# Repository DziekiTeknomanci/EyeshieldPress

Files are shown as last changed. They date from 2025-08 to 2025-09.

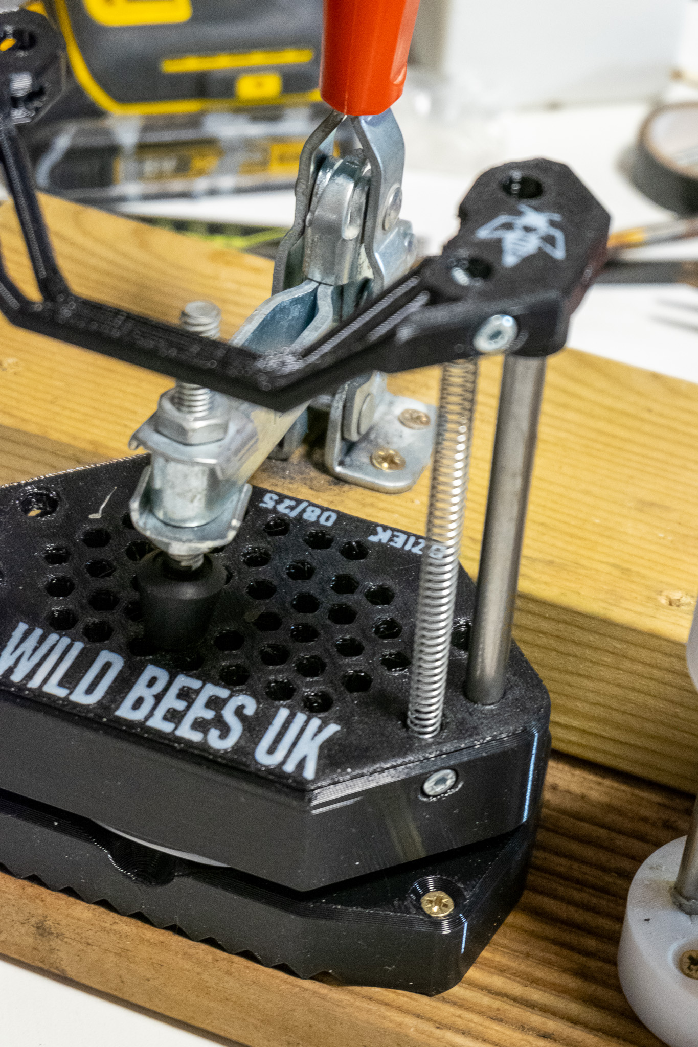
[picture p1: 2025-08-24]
Photos/DSCF0192.jpg

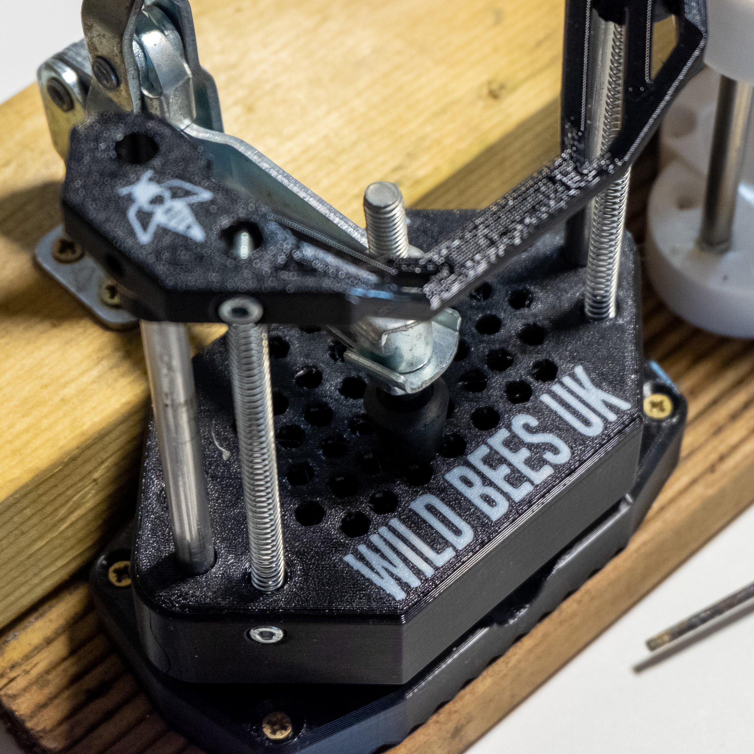
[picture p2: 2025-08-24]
Photos/DSCF0189.jpg

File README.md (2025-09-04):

## Bill of Materials (Hardware)

| Component | Qty | Example Link | Notes |
|---|:--:|---|---|
| M4 × 16 mm cap-head socket screws (CHSS) | 10 | [eBay](https://www.ebay.co.uk/itm/365366757336) | 20 mm also works. Cap-head looks neat, other heads are fine. |
| 8 mm linear rod, 150 mm length | 2 | [eBay](https://www.ebay.co.uk/itm/284132709444) | Cheaper in longer lengths—cut to size. (8 mm OD tube may work. Avoid threaded stud.) |
| LM8UU linear bearing | 2 | [eBay](https://www.ebay.co.uk/itm/283560168663) | Optional but highly recommended. |
| Expansion spring, 30–50 mm free length, 6–8 mm OD, 0.5–0.8 mm wire | 2–4 | [eBay](https://www.ebay.co.uk/itm/387764721266) | Two is usually enough; four anchor points allow tuning. |
| Toggle clamp | 1 | [Amazon](https://www.amazon.co.uk/dp/B08F4TG6J5) | Many types will work; large force not required. |

> You can modify the CAD to accommodate different hardware.

---

## Printed Parts & Settings

| Part | Qty | Walls | Solid Top/Bottom Layers | Infill | Notes |
|---|:--:|:--:|:--:|:--:|---|
| Press Bottom | 1 | 3 | 4 / 3 | Gyroid 10% (or Grid 20%) | — |
| Press Top | 1 | 3 | 3 / 4 | Gyroid 10% (or Grid 20%) | — |
| Press Cap | 1 | 3 | 3 / 3 | Gyroid 10% (or Grid 20%) | Tree support recommended for the overhang |
| Printed “Bearing” (optional) | 2 | 4 | 3 / 3 | **None (solid)** | Only if not using LM8UU; print at minimal layer height |

### Material Options
- **PETG** — Recommended for all parts.
- **PLA** — Works, but watch heat buildup; press faces may creep over time.
- **ABS** — Most durable; scale to ~**101%** or compensate for shrinkage in CAD.

### Logos/Text Variants
- *Plain:* Slice the “plain” STL, or in the 3MF set both “objects” to the same filament.
- *Embossed:* Delete the non-named objects in the 3MF; the text will be cut into the first layer.

### Printing With Contrast Colour
The logo/text versions use two bodies at Layer 1 so you can do a manual or automatic filament change for contrast. If you print **Top** and **Cap** together, you only need one change. PLA text on a PETG body is fine. Prefer the provided 3MF files so objects are already separated by filament.

---

## Tools & Consumables
- Soft hammer/mallet *(or steel hammer + wood block)*
- Vice or clamp *(for pressing LM8UU)*
- Lithium or other heavy grease *(light oil works but is sub-optimal)*
- 4×2″ timber off-cut (base & raised step)
- Hacksaw + sandpaper *(if cutting shafts)*
- **Optional:** M4 tap, 7.5 mm drill bit, 8 mm drill bit

---

## Assembly (≈10–20 min)

1. **Cut shafts (if needed).** If your 8 mm rod isn’t pre-cut, cut to **150 mm**. Tolerance is generous (> 10 mm), but make both the same length. Deburr and add a small chamfer with sandpaper. A cordless drill can act as a “lathe” while sanding.
2. **Prep threads.** *Press Top* and *Press Cap* include printed **M4** threads. Screws will self-tap; using an **M4 tap** makes it easier.
3. **Size holes.** Open up the outer holes on *Press Top* with an **8 mm** bit (hand-twisting is fine). Size the matching holes on *Press Bottom* and *Press Cap* to **7.5 mm** so the shafts fit tightly there.
4. **Install shafts (bottom).** Using a soft hammer, drive both shafts into the two large holes on *Press Bottom* until flush with the underside. Stack *Press Top* during this step to help alignment.
5. **Install bearings (top).** Pack **LM8UU** with heavy grease. Press them into the two 25 mm bores on *Press Top*. These are a friction fit—start gently with a mallet, then press fully using a vice or clamp.
6. **Assemble slide.** Carefully slide *Press Top* onto the shafts.
7. **Fit springs (lower).** Hook 2 springs into the lower anchor holes on *Press Top*. Pass the M4 socket screw through the spring loop and into the threaded hole. Do not overtighten. Up to 4 springs can be used.
8. **Fit cap.** Tap *Press Cap* onto the shaft ends. If loose, there is an **M4** hole to secure, but it’s usually not needed.
9. **Fit springs (upper).** Attach the spring tops to *Press Cap* as above.
10. **Mount to base.** Screw the press to a **wooden base**, then add a **raised “step”** 40–50 mm behind the base surface (a 4×2″ off-cut is perfect).
11. **Mount the toggle clamp.** Center the clamp over *Press Top* and adjust height so the press faces just meet. Extra clamp force only loads the press, not the work—there’s no benefit to overtightening and you can’t “over-press” the part unless you damage the tool.

---

## Tips
- Heavier grease inside LM8UU reduces rattle and wear; avoid losing balls from the open ends.
- If press fit tolerances are frustrating for your printer/material, consider lightly sanding bores or tweaking the CAD.
- Printed bushings work in a pinch but LM8UU will last longer and glide smoother.

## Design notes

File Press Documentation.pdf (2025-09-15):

## Hardware

## Printed Parts

## Material Options

## Assembly (about 10-20 mins)

## Assembly Steps

Component | Qty | Link | Note
M4x16mm CHSS | 10 | eBay | 20mm should be fine if you have it, cap-head are neatest but others will function.
8mm Linear Rod, 150mm | 2 | eBay | Bit cheaper if bought in longer lengths and cut. 8mm OD tube may be viable. Studding is awful!
LM8UU Linear Bearing | 2 | eBay | Optional but highly recommended
Expansion Spring, 30-50mm, 6-8mm OD, 0.5-0.8mm wire | 2-4 | eBay | If you already have an assortment, you may already have a suitable spring! 2 should be enough, but there's 4 mounts so you tweak it as needed.
Toggle Clamp | 1 | Amazon | Many others will be suitable, large clamping force not required
Component | Qty | Note | Walls | Solid Top/Bottom Layers | Infill
Press Bottom | 1 | | 3 | 4/3 | Gyroid - 10%, or Grid - 20%
Press Top | 1 | | 3 | 3/4 | Gyroid - 10%, or Grid - 20%
Press Cap | 1 | Tree support recommended on overhang | 3 | 3/3 | Gyroid - 10%, or Grid - 20%
Printed 'Bearing' (Optional) | 2 | If not using LM8UU (not recommended). Use minimal layer height | 4 | 3/3 | None (solid)
PETG | Recommended for all parts
PLA | Likely okay, but be mindful of heat buildup, press surfaces may deform over time
ABS | Scale to 101% or measure + compensate shrinkage manually, most durable but awkward

Press Top/Press Cap have optional text/symbols
Printing with contrast colour | Requires a manual or automatic filament change on layer 1. If you print these both together, you only need to change once. PLA text on a PETG main body is fine. Use 3MF files, objects should be preset to use different filaments.
Print without logo/text | Use the plain STL files, or let both global filaments to the same in your slicer with 3MF files
Print with embossed logo/text | Delete the non-named objects in the slicer and the text will be 'cut into' the first layer

Materials & Tools
Soft Hammer/Mallet/ Hammer + Wood Block Lithium Grease
4x2 Offcut or other scrap timber
Vice/Clamp (for pressing the bearings)
M4 Tap (optional)
7.5mm Drill Bit (optional)
8mm Drill Bit (optional)
Wood screws, length dependent on the timber used

Having a 7.5-8mm drill bit and an M4 tap is useful but optional. If cutting linear shaft, you will need a hacksaw and sandpaper.
If you haven't bought the shaft in 150mm lengths, cut it to 150mm lengths with a hacksaw. These have well over 10mm of tolerance, but its important they are both the same. Use sandpaper or other abrasive to sand a slight chamfer on the end. You can chuck the shaft in a cordless drill as a rudimentry lathe while sanding to make it nice and even!
Press Cap' and 'Press Top' contain printed M4 threads. Screws should self-tap, but if you have an M4 tap, use it to prepare the threads now. Use the 8mm drill bit (can be done by hand) to properly size the two outer holes on the on the 'Press Top' and the 7.5mm for the 'Press Bottom' and 'Press Cap'. The shaft should pass freely through 'Press Top' and be very tight on 'Press Bottom/Cap'.
Using a soft hammer (or steel hammer with some protective wood), carefully drive the shaft into the 2 large holes on 'Press Bottom' until the end of the shaft is flush with the bottom of the part. You can stack 'Press Top' on top to help with alignment.
Smear some heavy grease inside the bearings before starting, light oil can work but a heavier grease is much better. Bear in mind that the inside of the bearing is open, and you can lose ball bearings if abused! Set 'Press Top' flat-side down and insert the 2 bearings into the 2 large 25mm holes. These should be a friction-fit. I reccommend getting them started very gently with a soft hammer, then using a vice or clamp to press them in. Please let me know if tolerances are a frustration and I'll find a more robust method of retaining it, or feel free to modify the CAD file yourself. Then carefully slide 'Press Top' onto the two shafts.
Fit two springs to 'Press Top'. Insert through one of the four holes on the top so the loop is aligned with the screw hole, then pass the shaft of the socket screw through the loop and screw it into the threaded hole. Do not overtighten, it is hard to undertighten. You can add up to 4 springs if needed.
Fit the cap by carefully tapping it onto the end of the linear shaft. If it is loose, there is an M4 screw hole that can be used to help secure it, but it shouldn't be needed.

You can always modify the CAD file to accomodate different hardware!

Fit the top of the springs to 'Press Cap' in the same manner as 'Press Top'
Prepare the wooden base, you need a base part to screw the press down to, then a raised 'step' just behind about 40-50mm higher than the base, a 4x2" offcut is perfect.
Screw the toggle clamp to the raised shelf so that it is centred on the 'Press Top', adjust the clamp height so that the the two press surfaces make contact, any excess clamping force is transferred to the press rather than the patch, so there is no benefit of overtightening, but equally, you can't 'over-press' the patch, it is only too tight if its enough to damage the tool

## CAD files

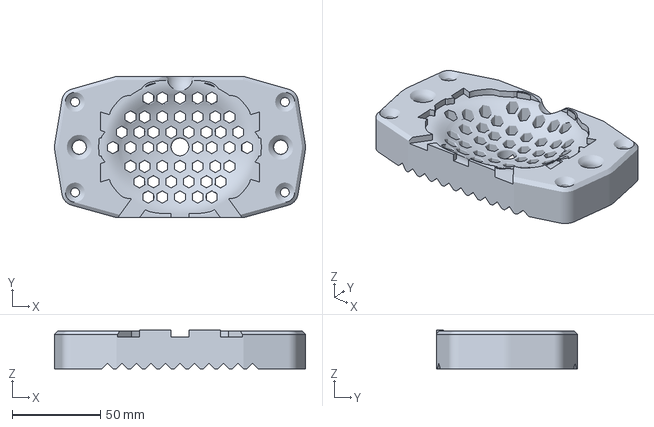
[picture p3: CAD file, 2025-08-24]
Meshes/3MF/PressBottom.3mf
142.0 x 80.0 x 22.0 mm

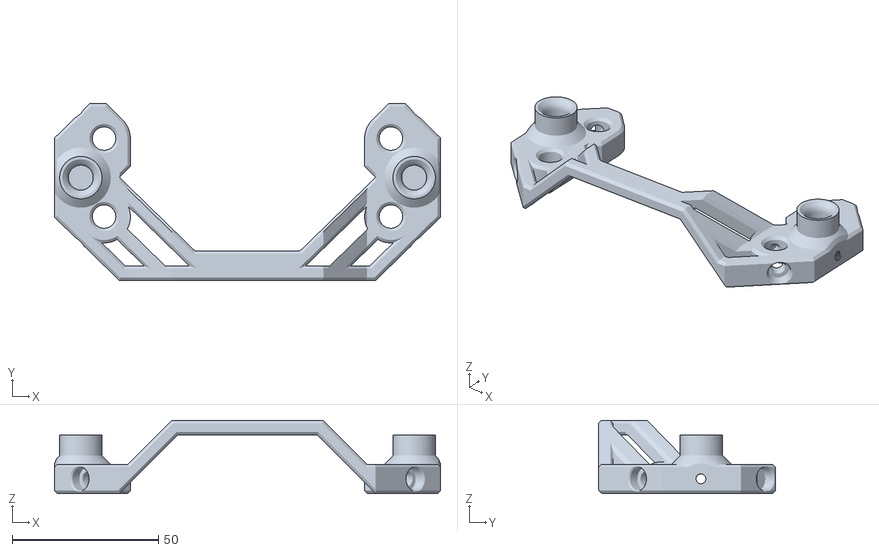
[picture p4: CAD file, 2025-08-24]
Meshes/STL/PressCapRaw.stl
132.0 x 60.5 x 25.0

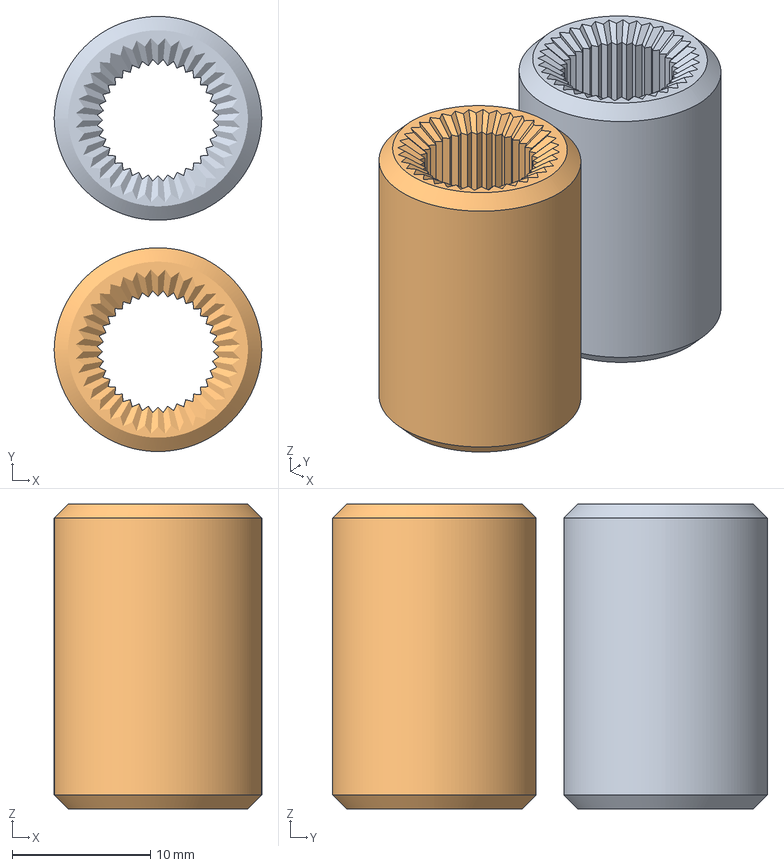
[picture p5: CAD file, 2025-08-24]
Meshes/3MF/PrintedBearing.3mf
15.0 x 31.4 x 22.0 mm
PrintedBearing.stl x 2

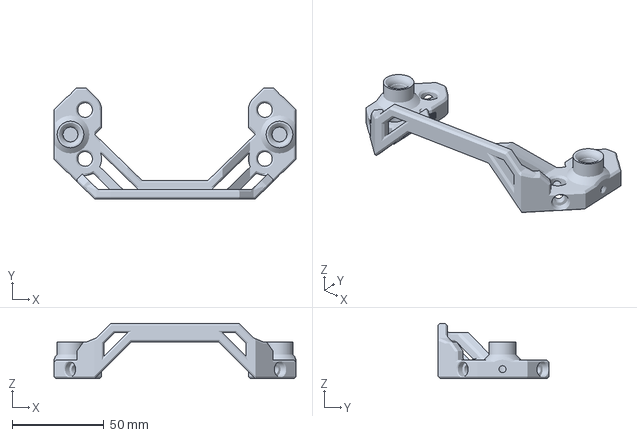
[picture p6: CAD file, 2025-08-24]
Meshes/3MF/PressCap.3mf
132.0 x 60.5 x 30.0 mm

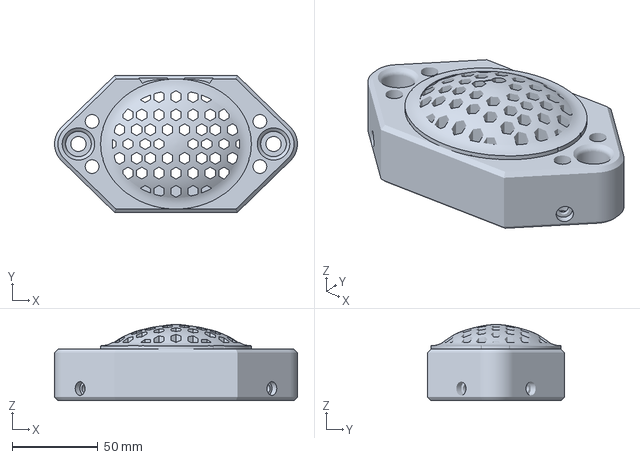
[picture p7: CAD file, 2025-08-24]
Meshes/3MF/PressTop.3mf
142.0 x 80.0 x 44.4 mm

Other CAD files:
Meshes/STL/PressBottom.stl
Meshes/STL/PressCap.stl
Meshes/STL/PrintedBearing.stl
